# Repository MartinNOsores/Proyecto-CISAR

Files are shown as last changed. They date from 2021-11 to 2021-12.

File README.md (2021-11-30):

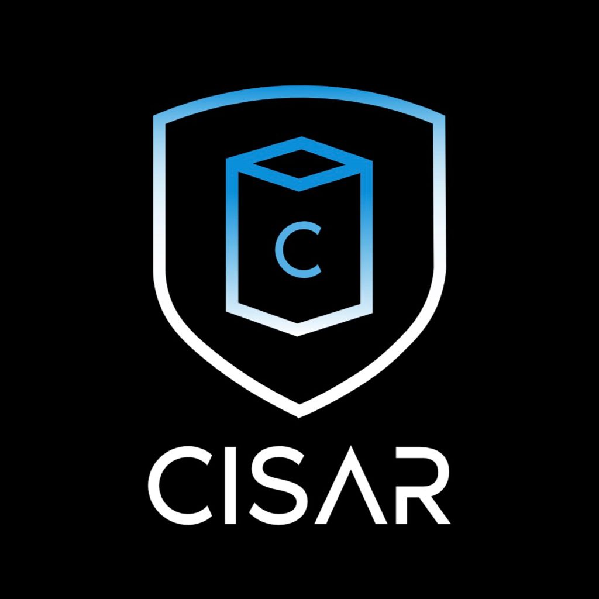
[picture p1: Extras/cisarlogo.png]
LogoCisar

# __Proyecto CISAR 2021 ™__

# Objetivo:
Nuestro proyecto “Cisar” consiste en un sistema de desinfección y monitoreo eficaz . Está pensado principalmente para que los lugares de gran cantidad de personas, que puedan tener un sistema de desinfección eficaz, controlada y organizada, previniendo el contagio de Covid-19, de todo el volumen de personas de manera automatizada, a través del uso adecuado del barbijo, control de temperatura corporal, la oxigenación en sangre e incitación a esterilizar las manos, el cuerpo en su totalidad y los objetos personales.
Para esto se construirá una cabina sanitizante y un control esterilizador de objetos personales.

# Temática:
Debido a la situación que estamos viviendo actualmente a nivel mundial, se debe tener una gran responsabilidad en relación a los cuidados que tomamos y más aún en lugares donde concurre un gran volumen de personas. Ante esta problemática nos topamos con un modelo de cuidado ineficiente, por ello nuestra propuesta consta de un aparato que nos ayude a lograr esos cuidados de la manera más eficiente posible, reduciendo considerablemente las posibilidades de contagio, logrando un eficiente control de multitudes. Este proyecto está pensado puntualmente para colegios y empresas donde tienen gran volumen de alumnos, hipermercados y fábricas.

# Descripción general:
Nuestra propuesta ante el Coronavirus y su repercusión a nivel mundial, es una cabina con la capacidad de tomar la temperatura de la persona que ingresa, sensar la oxigenación en sangre, desinfectar con un rociado alcohol en las manos, y de detectar la correcta posición del barbijo mediante una cámara, con Inteligencia Artificial .
Para su funcionamiento en régimen normal, el sistema estará enchufado a un cable de red común, de 220v.

Debe tener una cámara que mediante una Raspberry, y un programa ya entrenado de Inteligencia Artificial; identificará la correcta posición del barbijo, en este caso, le mostrará a la persona en una pantalla si está todo dentro de los parámetros correspondientes (Temperatura corporal, Oxigenación en sangre y el tapa boca), dándole acceso a la institución. De lo contrario, le indicará cómo debe ir colocado el tapabocas o cómo proceder ante la detección de una temperatura considerada como fiebre y dará aviso a las autoridades de la institución para que tengan la precaución correspondiente.

Se llevará un registro mediante el cual quedarán asentadas la cantidad de personas que ingresen a la institución, con su horario de ingreso respectivo, su temperatura, y si tenía bien colocado el tapabocas en el primer escaneo que realiza el sistema.

# Segmento de Usuario:
## Ventajas:
1. Desinfecta a los usuarios en cuestion de segundos.
2. No utiliza quimicos nocivos para la salud.
3. Promueve la higiene personal e incitacion a lavarse las manos.
4. Fomenta el cuidado del medio ambiente con el uso de materiales reciclados.
5. Garantiza espacios completamente libres de virus.

# Logros:
-  🥇 Project Idea ONIET 2021
-  🥇 Sello de Identidad ONIET 2021
 
# Integrantes:
  ## *Gonzalez Nuñéz Pedro*
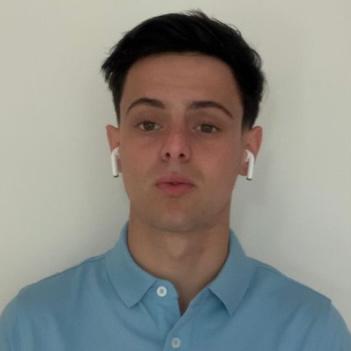
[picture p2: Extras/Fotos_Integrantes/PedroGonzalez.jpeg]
  
  ### Contacto: 
  - Instagram: @pedro_gonzalez_
---
  ## *Osores Martin Nicolás*
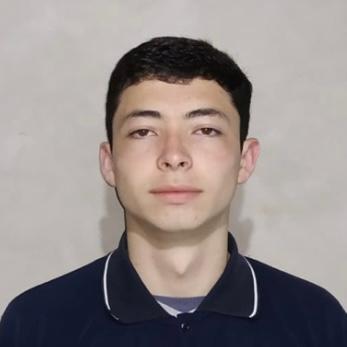
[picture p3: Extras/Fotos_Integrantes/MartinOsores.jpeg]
  
  ### Contacto: 
  - Instagram: @martin_osores_
---
  ## *Palacios Laureano*
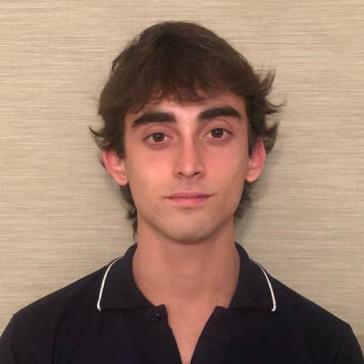
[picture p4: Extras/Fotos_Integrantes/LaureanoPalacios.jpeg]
  
  ### Contacto: 
  - Instagram: @laureanopalacios
---
  ## *Ruocco Julian Alberto*
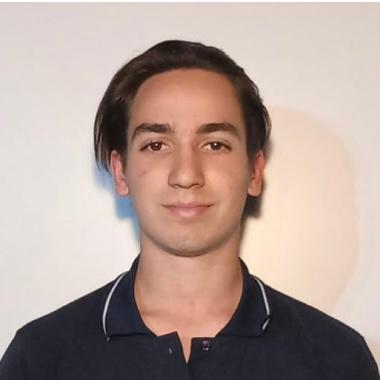
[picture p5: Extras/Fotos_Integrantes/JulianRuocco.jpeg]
  
   - Instagram: @julian_ruocco
---

## Nuestras Redes:
  - [Instagram (@cisar_cabinas_)](https://instagram.com/cisar_cabinas?utm_medium=copy_link)

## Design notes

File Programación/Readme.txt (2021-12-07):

Este apartado es dedicado a la programación, en el cual se incluirán los códigos de prueba y el main.

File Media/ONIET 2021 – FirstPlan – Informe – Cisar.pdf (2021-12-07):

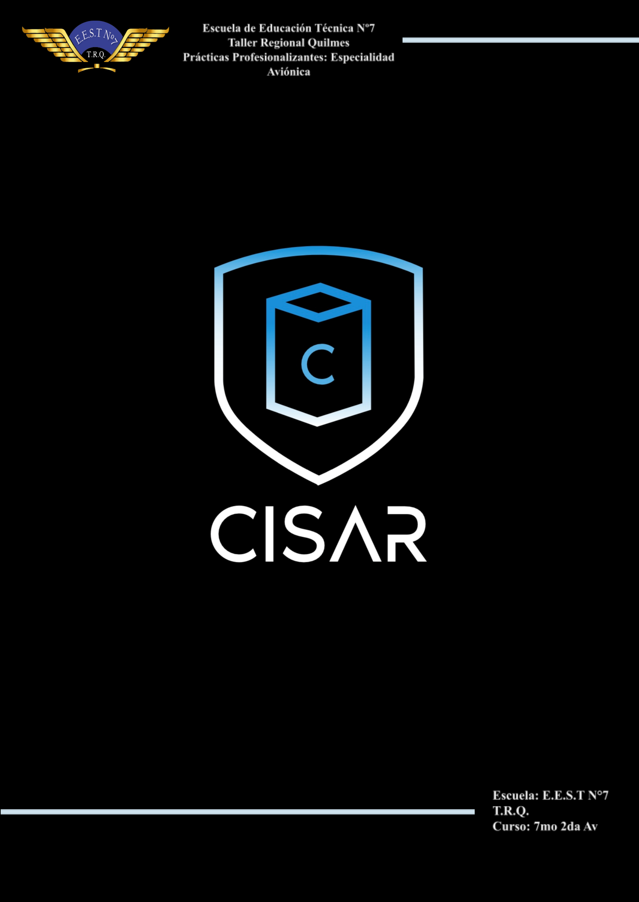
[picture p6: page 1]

# Introducción:

Descripción del producto: Cisar consiste en un sistema de desinfección y monitoreo focalizado para implementarse en lugares con gran concurrencia de personas. Este mismo consta de un sistema de desinfección corporal y objetos personales, de un control de acceso a los usuarios, un control del uso adecuado del barbijo y un control de enfermedades respiratorias.

# Informe de Canvas:

## Asociados clave:

Como asociados clave buscamos
- Para los insumos:
- Casa de electrónica como proveedor de componentes.
- Industria metalúrgica o entidades de reciclaje para el material estructural.
- Bulonera.
- Ferreteria industrial como proveedor de herramientas eléctricas.
- Casa de iluminación.
- Industria farmacéutica como proveedor del alcohol etílico.
- Colaboradores:
- Entidades de reciclaje
- Anmat
- Clientes con renta del producto.

## Actividades clave:

Como actividades clave tenemos:
- manejo de finanzas de manera que tengamos un buen margen de utilidad para destinar a reinversión.
- Servicio de logística: Encargada del envió del producto hasta el cliente
- Servicio de marketing por medio de redes sociales como instagram, facebook ads, contenido de youtube para atraer mayor inversión y llegar a mayores fronteras.
- Desarrollo del asistente virtual de manera que se proporcione ayuda al usuario.
- soporte al cliente, de manera que se garantice un correcto servicio hacia ellos.
- asistencia post-venta, para garantizar que al recibir el producto desarmado el cliente entienda cómo se debe armar el aparato.
- Servicio técnico para reparar el sistema o realizar calibraciones al producto.

## Recursos clave:

Los recursos clave con los que buscamos contar son:
- Estructura del producto.
- Plataforma tecnológica: Para permitir un espacio donde llevar a cabo
- Unidades de cómputo para permitir llevar a cabo todos los procesos del protocolo de Cisar.
- Plataforma de Telegram para contar con la interacción del asistente virtual.

## Propuesta de valor:

Como propuestas de valor ofrecemos:

- Reconocimiento del correcto uso del tapabocas.
- Una cabina autónoma con un control de acceso y de salud para los usuarios.
- Un sistema de desinfección de objetos personales con luces ultravioletas.
- Asistencia virtual de un bot de telegram para facilitar las interacciones entre la cabina y el usuario.
- Contamos con una estructura desmontable, para facilitar el traslado de la unidad.
- La aplicación de O3 para la sanitización del usuario.
- Ofrecemos la posibilidad de alquilar el producto en caso de no poder comprar el producto, donde el servicio técnico se ofrece gratuitamente.
●

●

Permite el cuidado entre los usuarios de una empresa

## Relación con los clientes:

La relación con los clientes se llevará a cabo mediante:
- Redes sociales:
- Instagram
- Facebook
- Whatsapp
- Tik Tok
- Sitio web

## Canales:

Los canales para llegar al cliente potencial se llevarán a cabo mediante:
- Instagram y Facebook, donde se contará con la página oficial de Cisar en perfil empresa de manera pública.
- Youtube, donde se subirán videos a manera de tutoriales por personal capacitado donde enseñarán todo lo necesario para utilizar el producto y se subirán videos enseñando los diversos sitios que cuentan con este producto y las ventajas que les trajo el utilizarlo.

- En Whatsapp y Telegram se contará con un perfil de empresa, el cual estará a disposición de las consultas de los usuarios.
- El Sitio web donde se mostrará geográficamente qué lugares utilizan Cisar y por qué así lo han decidido, además de infografías explicando el aparato y todas sus utilidades y aplicaciones.

## Segmento de clientes:

- Pymes que cuentan con oficinas.
- Fábricas con gran asistencia de personal.
- Hospitales con sectores de acceso especial.
- Laboratorios de análisis médicos.
- Instituciones educativas.

## Estructura de costos:

- Infraestructura tecnológica, principalmente la cabina y su electrónica.
- Servicio de logística para permitir el envío del producto.
- Servicio de marketing para lograr alcanzar a más clientes potenciales.
- Servicio técnico especializado para garantizar el correcto mantenimiento del producto.

## Vías de ingreso:

- Cobro por venta de unidad del producto.
- Tarifa variable con relación a la demanda del mismo producto.
- Cobro por alquiler de unidad del producto.
- Costo extra por especificaciones en la demanda del cliente (agregado).
- Métodos de pagos: Credito / Debito / Efectivo

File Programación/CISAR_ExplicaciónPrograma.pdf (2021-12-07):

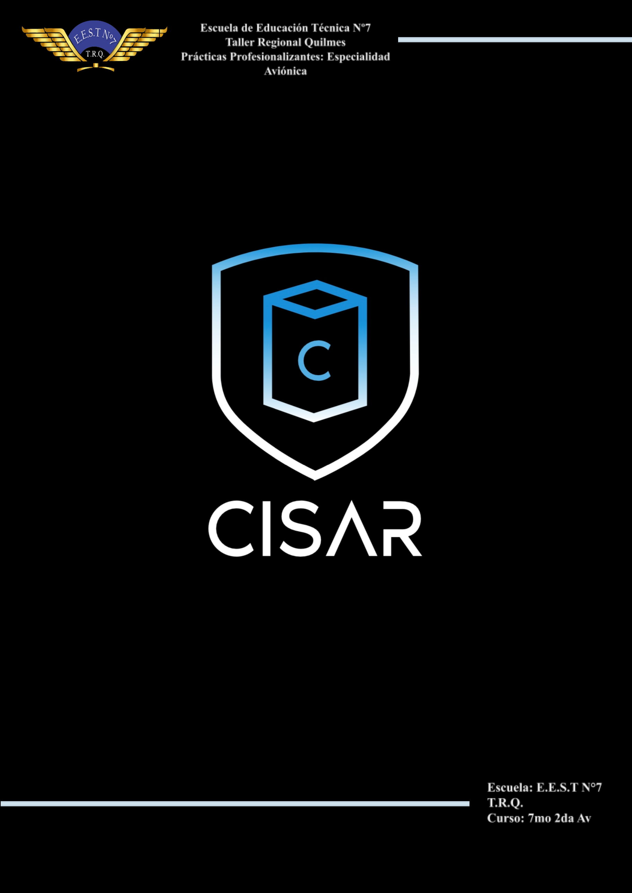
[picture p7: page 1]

# Explicación Programa Categoría: Project Idea

2021

### Informe descriptivo de la programación principal en Raspberry:

Empezamos importando las librerías que necesitamos:

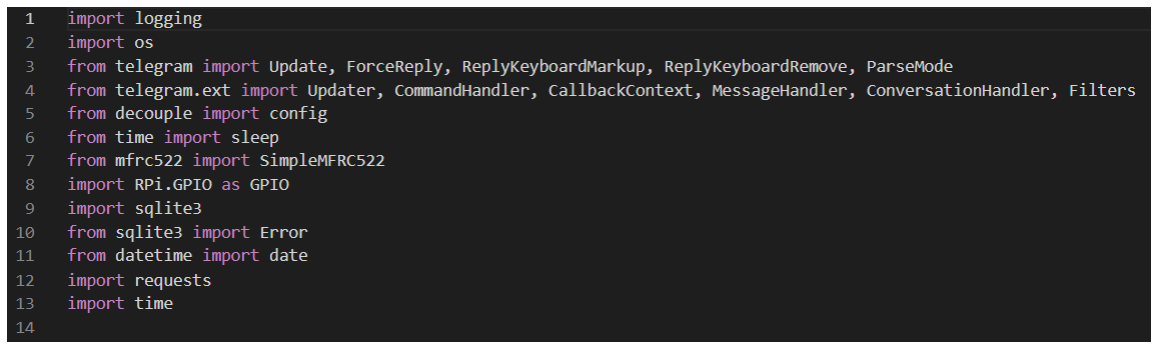
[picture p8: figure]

Creamos las variables y listas que necesitamos:

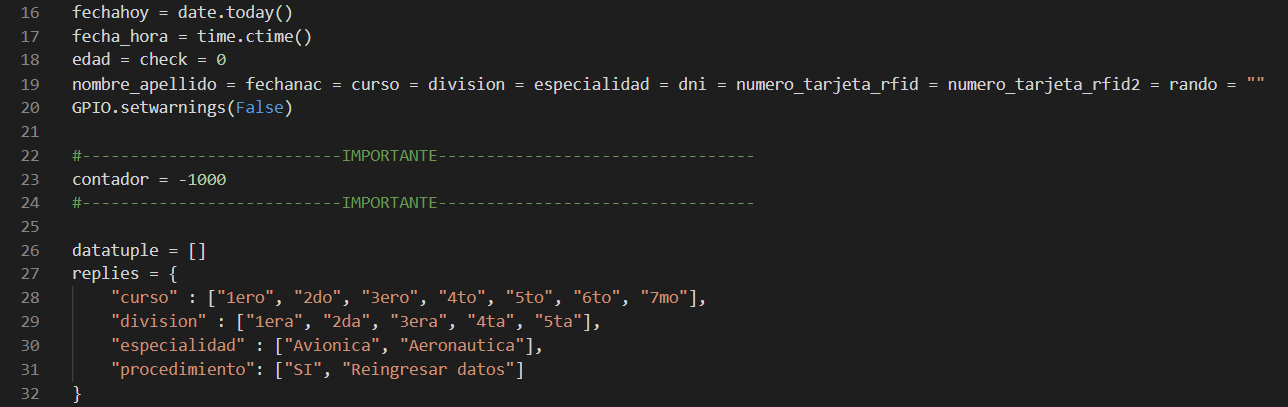
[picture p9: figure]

Se ejecuta el main, donde se inicializa el updater, dejando el programa a la escucha de recibir un mensaje:

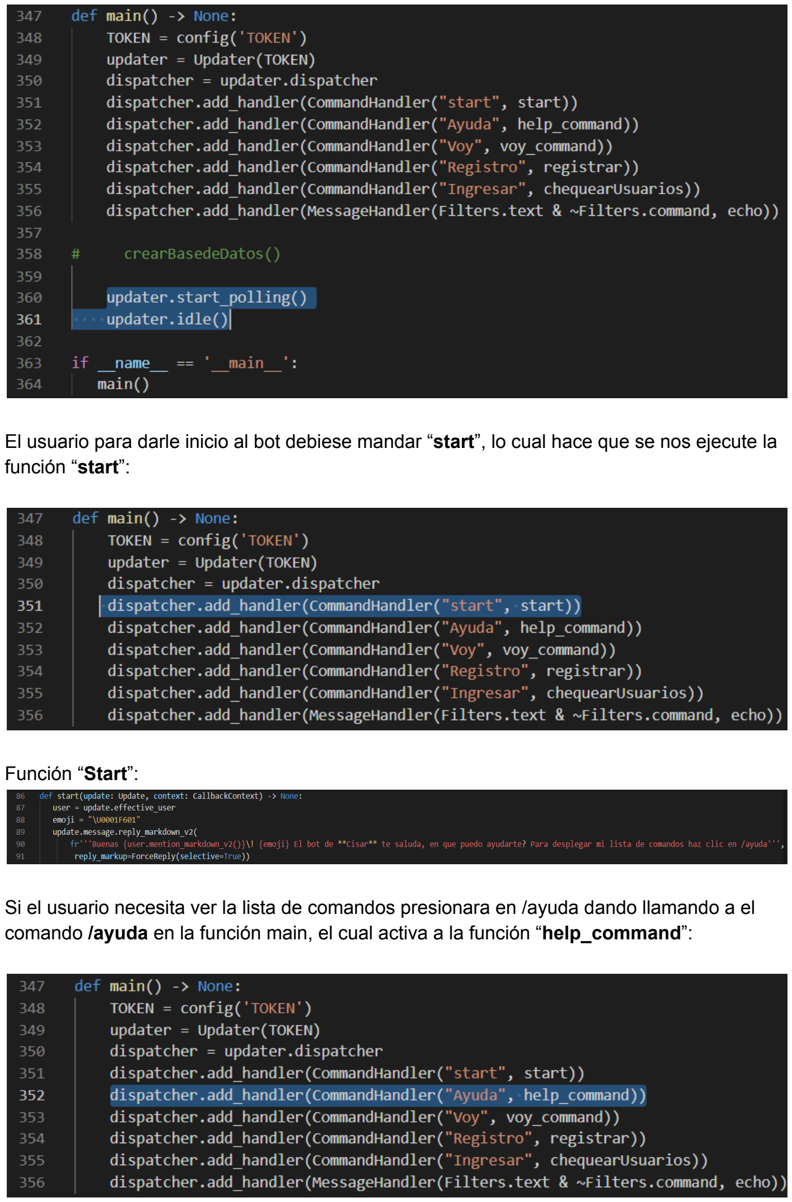
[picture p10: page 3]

El usuario para darle inicio al bot debiese mandar “start”, lo cual hace que se nos ejecute la función “start”:

Función “Start”:

Si el usuario necesita ver la lista de comandos presionara en /ayuda dando llamando a el comando /ayuda en la función main, el cual activa a la función “help_command”:

El usuario selecciona que comandó quiere utilizar:

- En el caso de seleccionar /Registro:
se llamará al comando /Registro dentro del main, donde este a su vez llamará a la función “Registrar”:

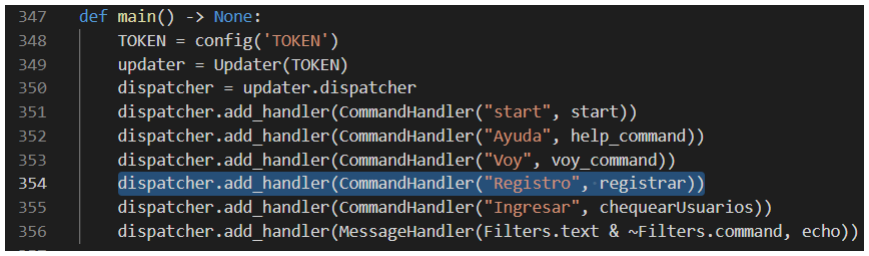
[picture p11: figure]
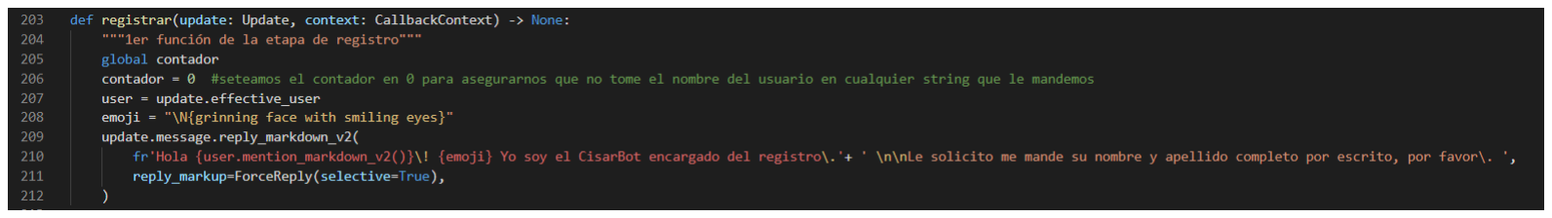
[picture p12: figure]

Nos solicitará que enviemos nuestro nombre y apellido completo, para lo cual mandaremos esto en formato de texto, dando como resultado el llamado a la función “echo” desde el main:

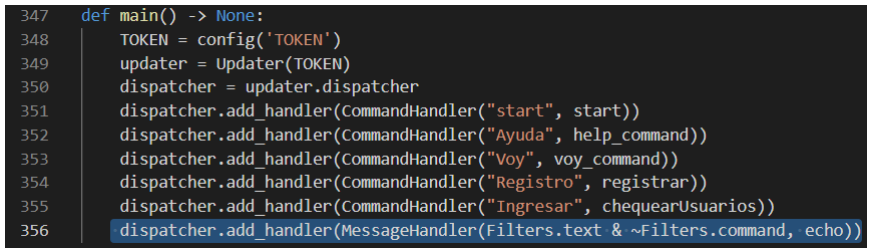
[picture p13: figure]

Previamente en la función “registrar” seteamos el contador en 0, de manera que cuando mandemos texto luego de dicha función, el programa entienda que es el nombre y apellido. En caso de mandar un nombre con números se seteara otra vez el contador en cero y se le solicitará al usuario su reingreso de este dato. Finalmente una vez que el usuario cargue un nombre válido se llamará a la función “registro_uno”:

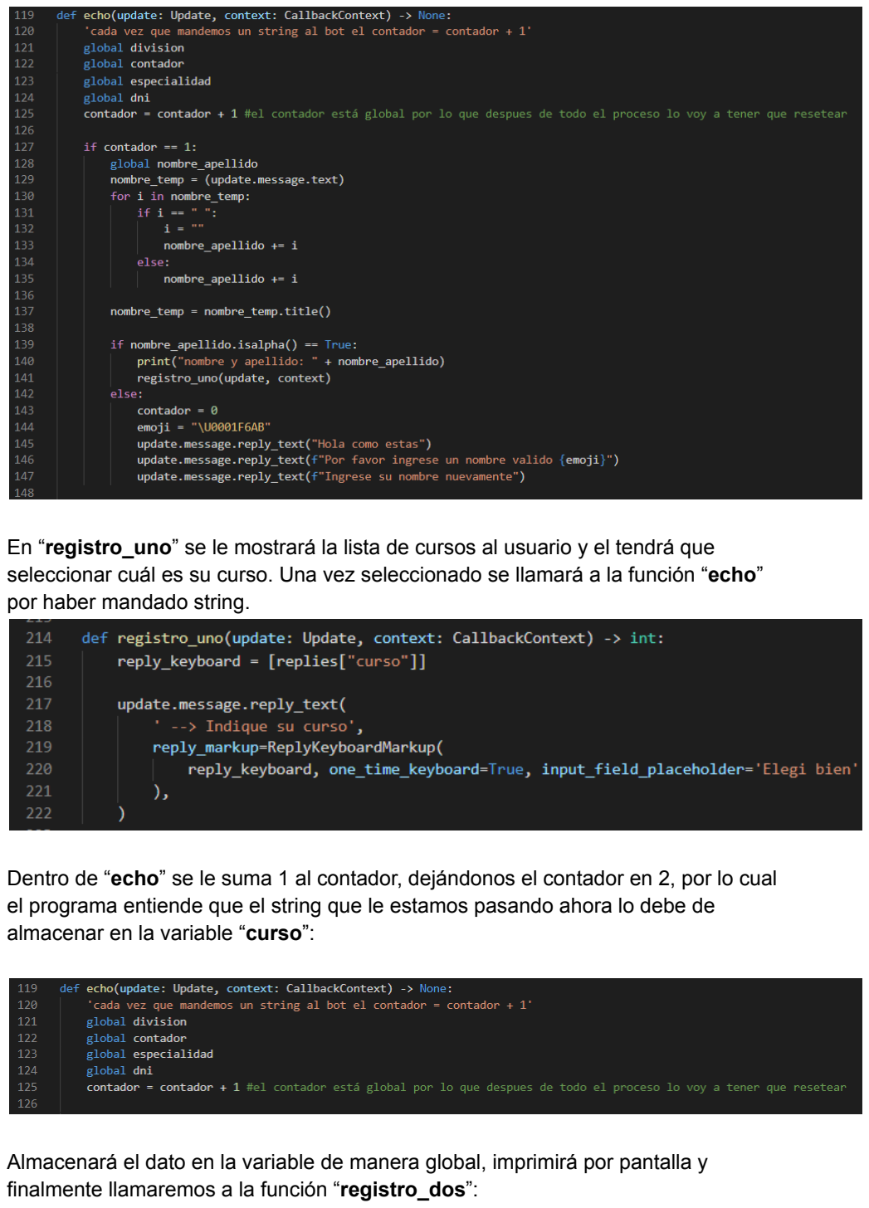
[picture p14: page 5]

En “registro_uno” se le mostrará la lista de cursos al usuario y el tendrá que seleccionar cuál es su curso. Una vez seleccionado se llamará a la función “echo” por haber mandado string.

Dentro de “echo” se le suma 1 al contador, dejándonos el contador en 2, por lo cual el programa entiende que el string que le estamos pasando ahora lo debe de almacenar en la variable “curso”:

Almacenará el dato en la variable de manera global, imprimirá por pantalla y finalmente llamaremos a la función “registro_dos”:

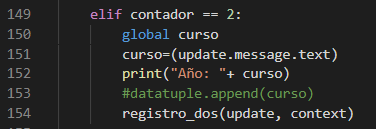
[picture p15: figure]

Dentro de la función “registro_dos” si el curso es 1ro, 2do o 3ero se mostrará la lista completa de divisiones para escoger a cuál pertenece. En caso de haber seleccionado previamente ser alumno de 4to, 5to, 6to o 7mo se mostrará la lista de divisiones recortando sólo las primeras 2 divisiones.
Una vez que el usuario seleccione su división se llamará a la función “echo”

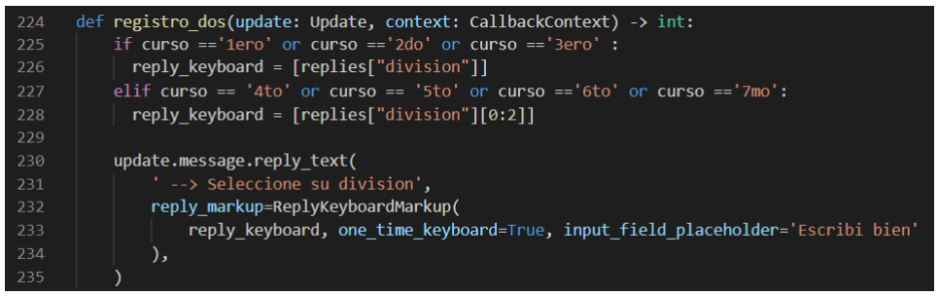
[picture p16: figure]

Al ingresar en “echo” aumenta el contador por lo cual tendría un valor de 3, con lo cual ingresará en la condición de que contador es 3, almacenará el string recibido en la variable (previamente declarada como global) “division”.
Si el curso seleccionado al momento de registrarse es 1ro, 2do o 3ero, imprimimos la división registrada y en la variable “especialidad” se almacenará un “-” y se llamará directamente a la función “registro_cuatro”.
En caso contrario, donde el curso del usuario en proceso de registro es 4to, 5to, 6to o 7mo, imprimimos por pantalla la división registrada y hacemos llamado a la función “registro_tres”:

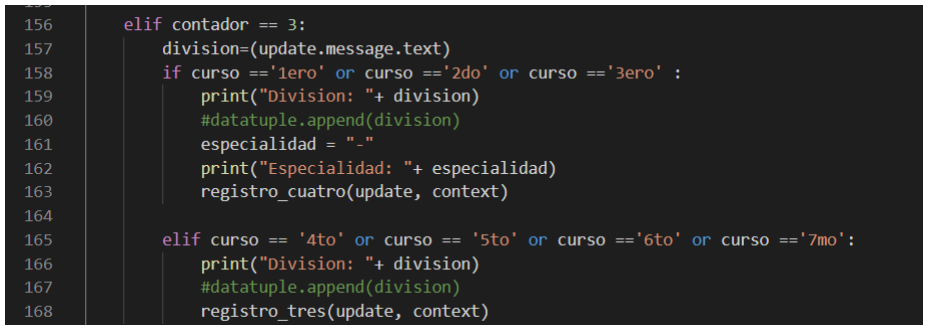
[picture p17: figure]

Se ejecuta “registro_tres”, donde se enseñará la lista de especialidad:

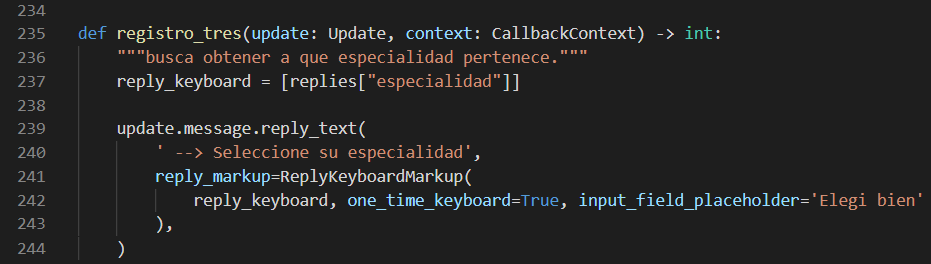
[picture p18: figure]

Una vez seleccionada la especialidad, se envía dicho string ingresando en la función “echo” aumentando el valor del contador en 1, dando como resultado que contador=4. Con la especialidad previamente definida como global, almacenamos el dato recibido en la variable “especialidad”, lo imprimimos por pantalla y realizamos el llamado de la función “registro_cuatro”:

Dentro de “registro_cuatro” declaramos al contador de manera global para posteriormente setearlo en 4 (esto es debido a que si el usuario coloco que pertenece a un curso de ciclo básico, su especialidad quedó definida como “-” y el contador se quedó en 3, debiendo estar en 4 para pasar al registro de DNI y así ingresar correctamente en el apartado de DNI dentro de “echo”).
Finalmente le solicitamos al usuario que ingrese por teclado su número de DNI:

Con la variable DNI declarada previamente como global dentro de “echo” indicamos que el string recibido debe ser almacenado en la variable “dni”, además de indicar que si el número introducido tiene más de 8 dígitos, se setea el contador en 4 y se llamará a la función “registro_seis”, donde se solicitará que reingrese el dni (permitimos que el dni ingresado sea menor a 8 debido a que algunos de estos no llegan a 8 dígitos).
Si el dni ingresado cumple con los requisitos mencionados se llamará a la función “chequeoDeDatos”:

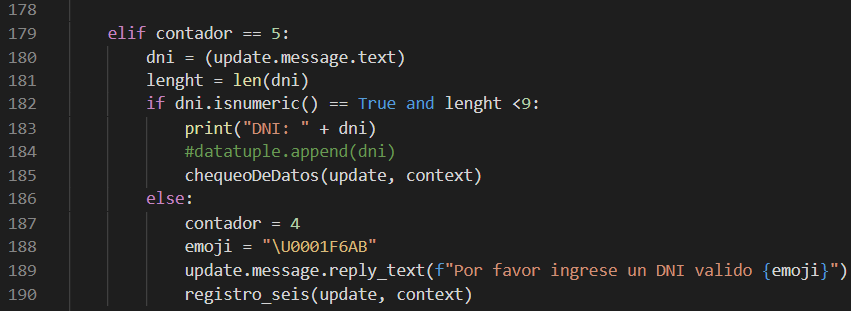
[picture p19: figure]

En “chequeoDeDatos” declaramos el contador de manera global, se ejecuta un mensaje pre-definido con los datos cargados por el usuario (almacenados en las variables) donde se pregunta si estos datos son correctos y se visualiza una lista de opciones “procedimiento” donde debe escoger entre “SI” o “Reingresar datos”.

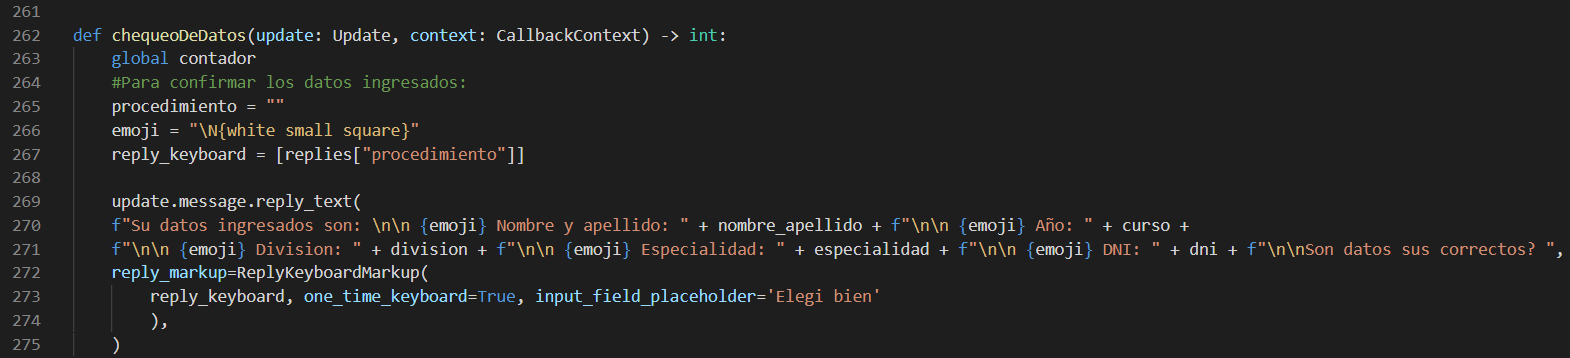
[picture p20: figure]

Una vez seleccionada la confirmación, ingresará en “echo” dando como resultado que contador = 6, donde se almacena el dato recibido en la variable local “procedimiento” y si seleccionó “Reingresar datos” el contador se seteará en -1000 (para evitar bugs) y se hará llamado a la función “registrar” para iniciar el proceso de registro desde 0.
En caso de haber seleccionado “SI” se llama a la función “registro_cinco”:

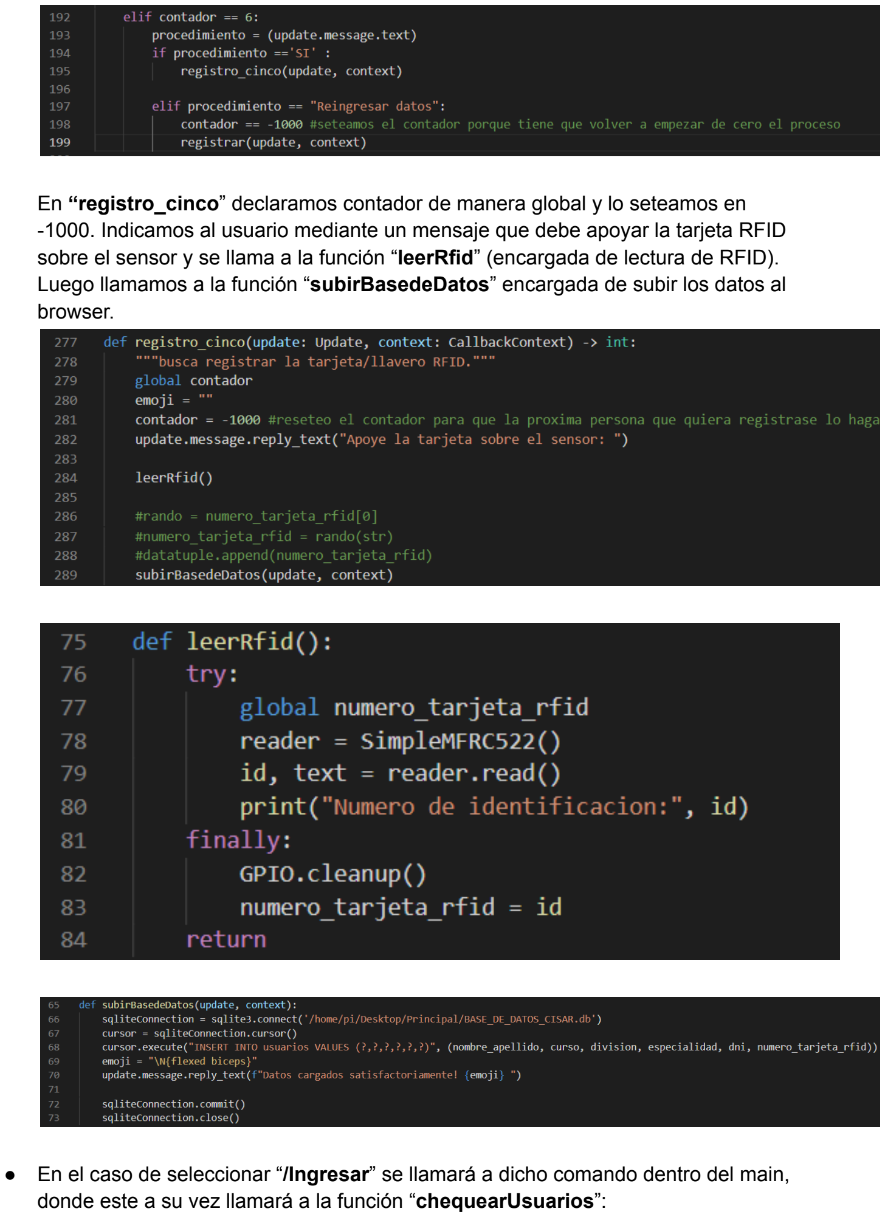
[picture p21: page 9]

En “registro_cinco” declaramos contador de manera global y lo seteamos en -1000. Indicamos al usuario mediante un mensaje que debe apoyar la tarjeta RFID sobre el sensor y se llama a la función “leerRfid” (encargada de lectura de RFID). Luego llamamos a la función “subirBasedeDatos” encargada de subir los datos al browser.

- En el caso de seleccionar “/Ingresar” se llamará a dicho comando dentro del main, donde este a su vez llamará a la función “chequearUsuarios”:

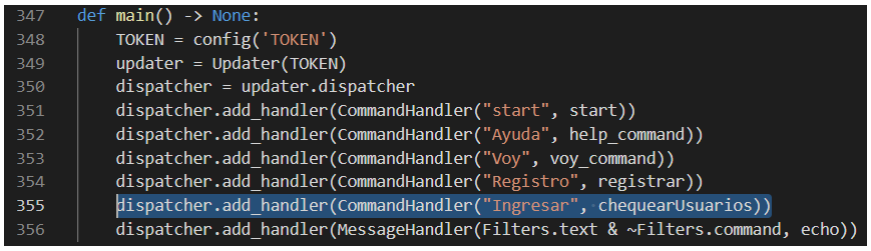
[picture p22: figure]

Dentro de la función “chequearUsuarios” se le enviará un mensaje al usuario indicando que debe apoyar la tarjeta sobre el sensor. Se llamará a la función encargada de la lectura del RFID “leerRfid” y se establecerá una conexión con el browser de la base de datos en búsqueda del número de identificación de la tarjeta asociado a un nombre, apellido, curso, división, especialidad y dni.
se declara la variable local “check” y se la setea en 0; de manera que el for se encargue de leer cada fila del registro tomado de la base de datos, una vez que encuentra al número de la tarjeta RFID almacenado en la base de datos toma el nombre, apellido, curso, división, especialidad y dni asociados a este número de tarjeta se le suma un 1 a “check” :

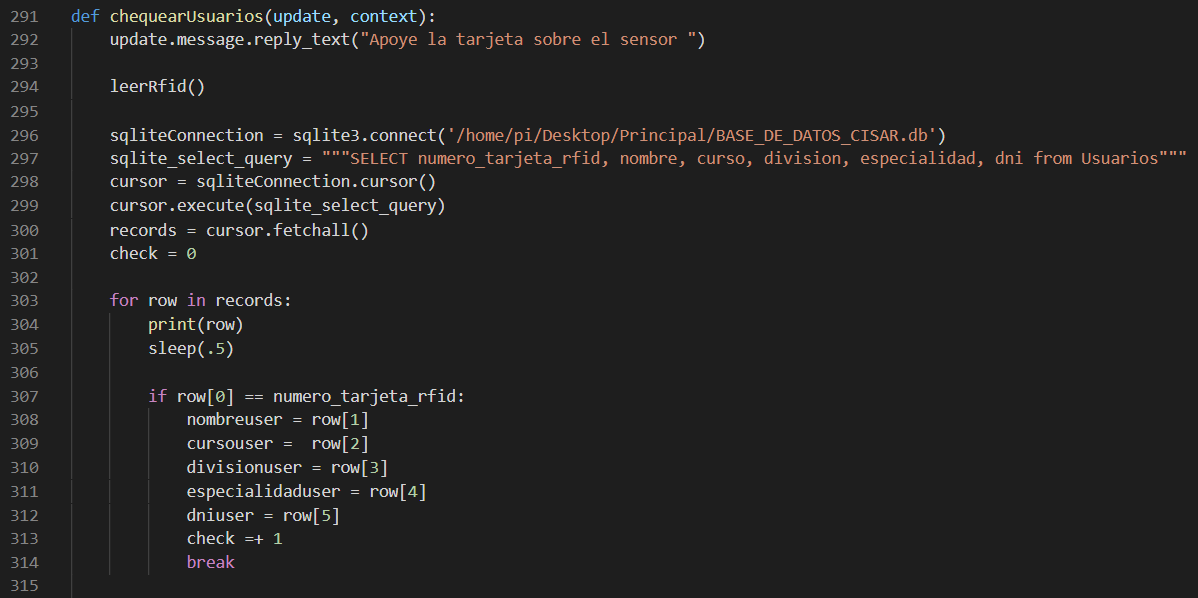
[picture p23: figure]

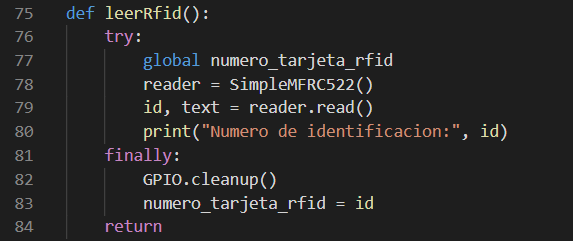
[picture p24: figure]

Por lo que evaluamos si “check” es mayor a 0, si es así declaramos a “pul” como variable global y enviamos un mensaje indicando al usuario que se encuentra en la base de datos, declaramos la variable local “pulsador” y le almacenamos el pin 40 de la Raspberry.
En cambio si “check” es igual a 0 se le envía un mensaje al usuario indicando que no se encuentra registrado en la base de datos y se ejecuta la función “ingreso_no_exitoso”.

Si recibimos un 1 (5V) desde la Arduino en el puerto de sensado de temperatura se ejecutará un mensaje pre-definido con las variables obtenidas de la base de datos previamente con destino el grupo de los directivos de la institución, a manera de alerta de sospechoso y se ejecutará la función “ingreso_sospechoso”
Por otro lado si no recibimos un 1 (5V) desde la Arduino en el puerto de sensado de temperatura se ejecutará la función “ingreso_exitoso”:

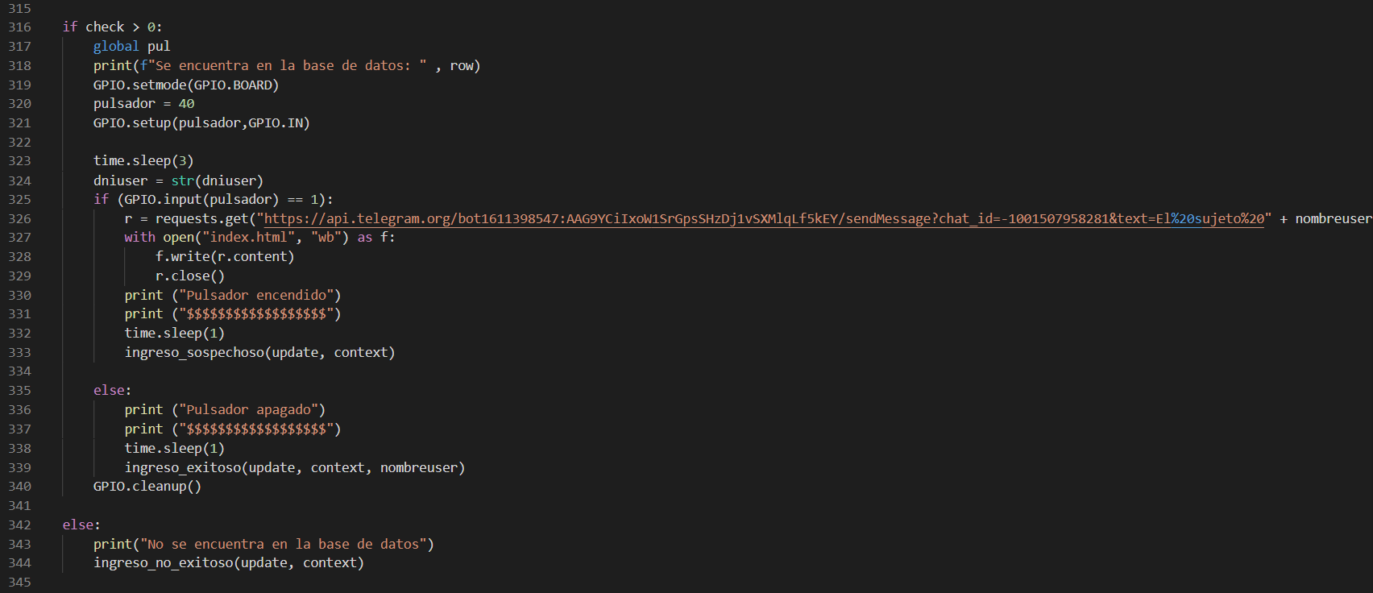
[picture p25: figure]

Dentro de la función “ingreso_exitoso”: Se le envía un mensaje al usuario indicando que puede ingresar a la cabina y deja un registro de fecha y hora del ingreso.

Dentro de la función “ingreso_sospechoso”: Se le envía un mensaje al usuario indicando que debe retirarse de la institución.

Dentro de la función “ingreso_no_exitoso”: Se le envía un mensaje al usuario indicando que no se encuentra registrado y se le enseña al usuario el comando para registrarse.

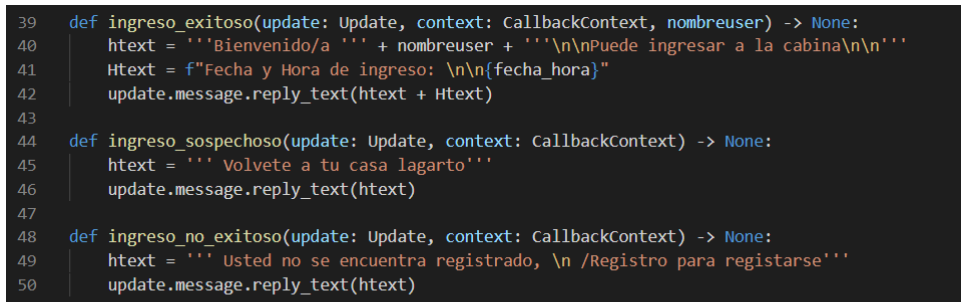
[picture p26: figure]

- En el caso de seleccionar /Voy, se llamará al comando /Voy dentro del main, donde este a su vez llamará a la función “voy_command”:

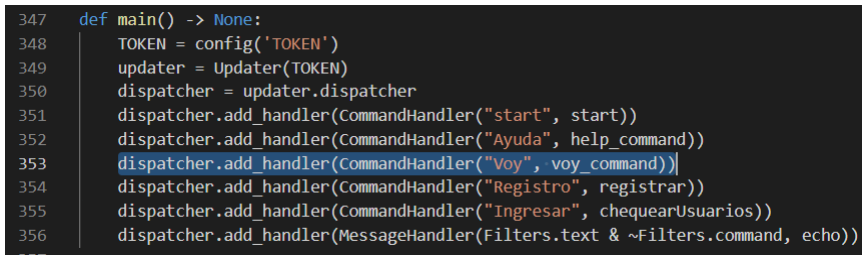
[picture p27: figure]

Se ejecuta la función “voy_command”, la cual envía le responde seleccionando el mensaje del usuario dentro del grupo de administración.

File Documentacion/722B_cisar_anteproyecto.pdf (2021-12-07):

Escuela de Educación Técnica Nº7
Taller Regional Quilmes
Prácticas Profesionalizantes: Especialidad Aviónica

# CISAR

## Presentación de anteproyecto

## Título del proyecto:

Tal como lo muestra el título vamos a realizar una cabina enfocada a la pandemia de COVID-19. Decidimos que el nombre del proyecto va a ser, CISAR (Cabina Integral Sanitizante Argentina), este nombre será especialmente utilizado para labores administrativas en este año, como también laborales en un futuro.

## Integrantes:

- GONZALEZ NUÑEZ, Pedro
- OSORES, Martín Nicolás
- PALACIOS, Laureano
- RUOCCO, Julián Alberto

## Objetivo del proyecto:

Nuestro proyecto “Cisar” consiste en un sistema de desinfección y monitoreo eficaz . Está pensado principalmente para que los lugares de gran cantidad de personas, que puedan tener un sistema de desinfección eficaz, controlada y organizada, previniendo el contagio de Covid-19, de todo el volumen de personas de manera automatizada, a través del uso adecuado del barbijo, control de temperatura corporal e incitación a esterilizar las manos, el cuerpo en su totalidad y los objetos personales.
Para esto se construirá una cabina sanitizante y un control esterilizador de objetos personales.

A continuación establecemos la construcción del proyecto en diversos objetivos:

1. Objetivo: Detectar los rostros del personal de la institución y dejar el registro de quién y a qué hora ingresó.
2. Objetivo: Sistema de sensado (sensor infrarrojo y sensor de temperatura), con rociador de alcohol.
3. Objetivo: Tener el generador de Ozono en funcionamiento.
4. Objetivo: Una estructura lo más hermética posible.
5. Objetivo: Sist de desinfección del calzado, Sensor de humedad
6. Objetivo: Página web.
7. Objetivo Opcional: Apartado pequeño con alcohol y luces ultravioleta para la sanitización de objetos personales (Como celular, billetera, etc).
8. Objetivo Opcional: Cabina especial para la desinfección de objetos personales

## Utilidades del proyecto:

Debido a la situación que estamos viviendo actualmente a nivel mundial, se debe tener una gran responsabilidad en relación a los cuidados que tomamos y más aún en lugares donde concurre un gran volumen de personas. Ante esta problemática nos topamos con un modelo de cuidado ineficiente, por ello nuestra propuesta consta de un aparato que nos ayude a lograr esos cuidados de la manera más eficiente posible, reduciendo considerablemente las posibilidades de contagio, logrando un eficiente control de multitudes. Este proyecto está pensado puntualmente para colegios y empresas donde tienen gran volumen de alumnos, hipermercados y fábricas.

A continuación comparto varios titulares de diferentes diarios que llevan a la misma conclusión, el virus durará un tiempo prolongado :

https://www.dw.com/es/opini%C3%B3n-el-coronavirus-lleg%C3%B3-para-quedarse/a-56113 832 (https://www.dw.com/es/opini%C3%B3n-el-coronavirus-lleg%C3%B3-para-quedarse/a-56113832)

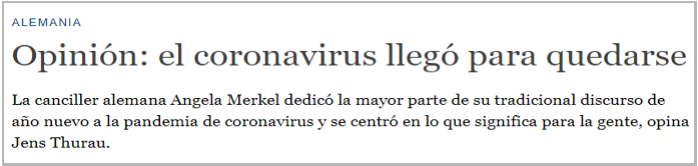
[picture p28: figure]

https://www.marca.com/tiramillas/actualidad/2021/03/18/605366d222601db9298b4597.html

https://www.lanacion.com.ar/politica/compra-de-vacunas-ya-se-gasto-la-mitad-del-presupuesto-y-solo-se-vacuno-al-099-de-la-poblacion-nid15032021/ (https://www.lanacion.com.ar/politica/compra-de-vacunas-ya-se-gasto-la-mitad-del-presupuesto-y-solo-se-vacuno-al-099-de-la-poblacion-nid15032021/)

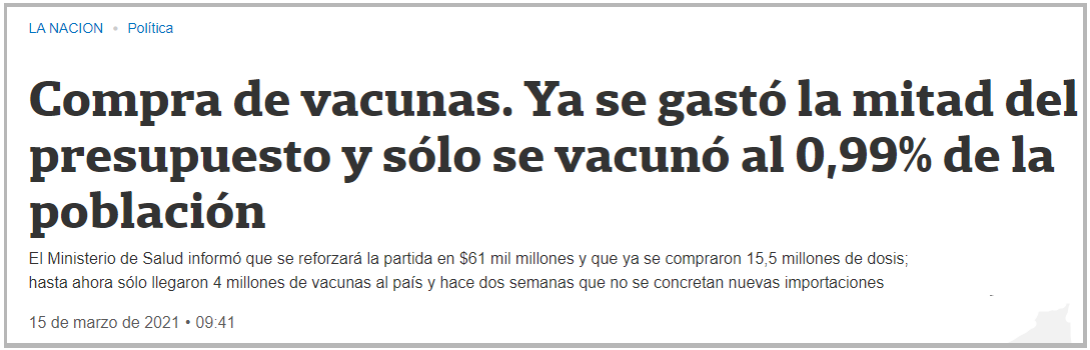
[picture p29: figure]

## Descripción del funcionamiento:

Nuestra propuesta ante el Coronavirus y su repercusión a nivel mundial, es una cabina con la capacidad de tomar la temperatura de la persona que ingresa, de desinfectar con un rociado alcohol en las manos, y de detectar la correcta posición del barbijo mediante una cámara, con Inteligencia Artificial .

Para su funcionamiento en régimen normal, el sistema estará enchufado a un cable de red común, de 220v. Pero tendrá una batería para poder continuar su funcionamiento al menos por dos días ante una emergencia eléctrica.

Debe tener una cámara que mediante una Raspberry, y un programa ya entrenado de Inteligencia Artificial; identificará la correcta posición del barbijo, en este caso, le mostrará a la persona en una pantalla si está todo dentro de los parámetros correspondientes (Temperatura corporal y el tapa boca) y le dará acceso a la institución. De lo contrario, le indicará cómo debe ir colocado el tapabocas o cómo proceder ante la detección de una temperatura considerada como fiebre y dará aviso a las autoridades de la institución para que tengan la precaución correspondiente.

Se llevará un registro mediante el cual quedarán asentadas la cantidad de personas que ingresen a la institución, con su horario de ingreso respectivo, su temperatura, y si tenía bien colocado el tapabocas en el primer escaneo que realiza el sistema.

## Análisis de factibilidad:

En este proyecto vamos a tener una gran variedad de tareas, donde se van a ver marcados en los siguientes puntos.

- Investigación:
- Acá vamos a desarrollar la información y las necesidades de cada parte del proyecto, incluyendo los alrededores del proyecto (condiciones/necesidades de las personas) para poder solucionar la mayor cantidad de problemas de cada persona. Los cuatro integrantes trabajaremos en este apartado para acotar tiempos y abarcar más puntos, además de que todos partamos desde la misma base.
- Investigando la proporción adecuada del uso del ozono, refracción de los espejos y sus ángulos para lograr una desinfección adecuada de los objetos.

- Diseño:
- Trabajaran Osores y Palacios, donde se utilizará principalmente el programa SolidWorks, donde haremos distintos prototipos de cabinas sanitizantes, para no quedarnos con simplemente uno.
- A partir de un prototipo veremos los materiales necesarios y gracias a esto podremos investigar el costo de cada uno.
- Estructura:
- Debe tener ciertas características, las cuales son: Poco peso, debe ser resistente, que sea de fácil armado/desarmado, que sea de fácil transporte, que no sea un material de corrosión rápida, que no sea un material poroso(para disminuir la adherencia de microorganismos indeseados), y que sea lo más económico posible.
- Estamos considerando la aplicación de hierro cuadrado y policarbonato alveolar.
- Página Web:
- Trabajarán Gonzalez y Ruocco, la van a hacer puramente con código, no se van a utilizar bases como las que ofrece “wix” o páginas por el estilo, sino que se van a usar las estructuras de HTML y los estilos con CSS.
- Sist de Ingreso de personas:
- Al ingresar una persona, primero tiene que dejar sus pertenencias en la máquina sanitizante de objetos, donde tendrá que seguir con el protocolo de ingreso. Para esto utilizaremos una lámpara led UV C y unos espejos que refractan la luz germicida para lograr una cobertura total.
- Al entrar, tiene que limpiarse el calzado en la alfombra desinfectante, donde se podrá tomar la temperatura, si no posee fiebre tiene que pasar las manos por el sensor infrarrojo, que se le agrega alcohol diluido con agua. Luego tendrá que ver hacia la cámara para poder saber si tiene bien puesto el barbijo, (gracias a la Inteligencia Artificial) se le mostrará cómo hacerlo.
- Dentro de la cabina hay un cierto margen de ozono en el ambiente, esto será previamente investigado para utilizar la proporción adecuada de ozono.
- Sistema de Actividad:
- Este sistema se desarrollará dentro de la IA (Inteligencia Artificial). Donde se podrá ver la cantidad de personas que entran y de ahí se podrá calcular la actividad por hora en ese mismo lugar. El cual será hecho con Python.

## Diagrama en bloques del prototipo:

Un diagrama en bloques muestra cada parte del sistema a finalizar y como se relacionan entre sí. Recomendamos el uso de miro (https://miro.com/) que es una herramienta muy práctica

Este es nuestro diagrama en bloques:


## Diagrama de tiempo de desarrollo:

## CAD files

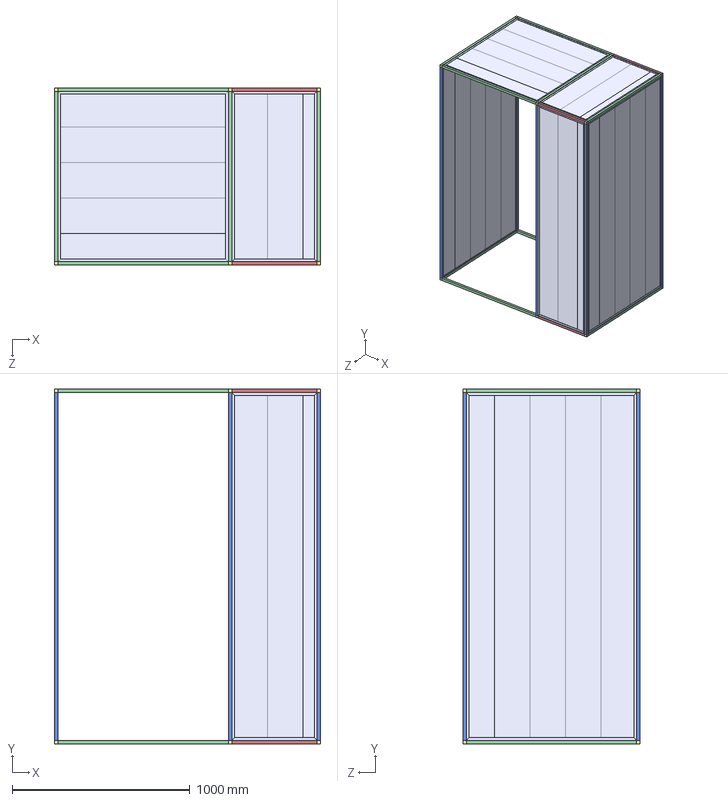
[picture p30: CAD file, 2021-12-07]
Modelado 3d/EnsamblajePrototipo.STEP
1500.0 x 2000.0 x 1000.0 mm
Ca隳 largo x 6
Ca隳 corto x 4
Ca隳 mediano x 10
Union 3 brazos x 8
Union 4 brazos x 4
Perfil J mediano (1mt) x 12
Perfil J Largo (2mt) x 10
Perfil J Corto (50cm) x 6
Tabla PVC 20cmx7mm Larga (2Mts) x 16
Tabla PVC 155mmx7mm Larga (2Mts) x 3
Tabla PVC 75mmx7mm Larga (2Mts) x 2
Tabla PVC 20cmx7mm Corta (1Mt) x 6
Tabla PVC 75mmx7mm Larga (1Mt)
Tabla PVC 155mmx7mm Corta(1Mt)

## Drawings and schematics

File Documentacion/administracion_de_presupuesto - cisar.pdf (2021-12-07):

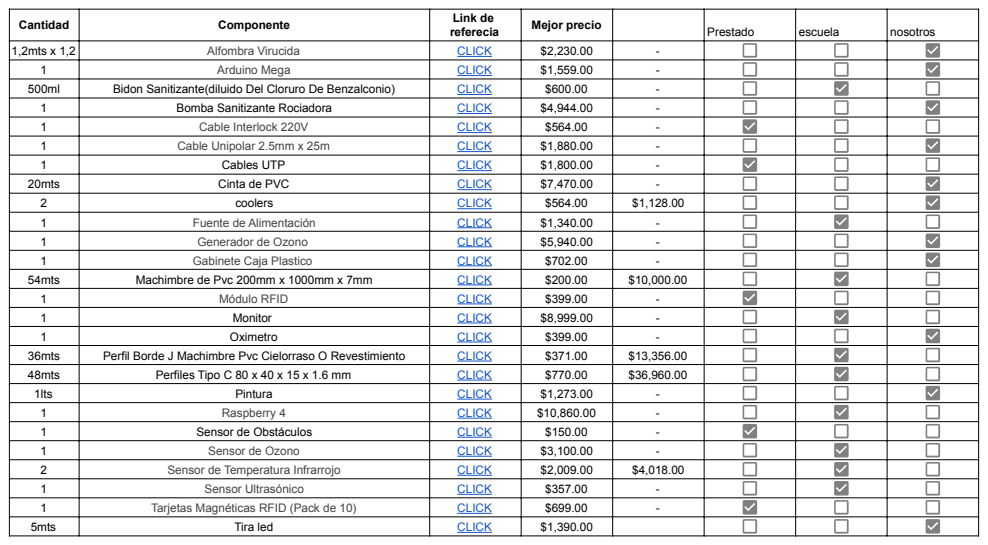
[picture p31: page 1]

Cantidad | Componente | Link de referecia | Mejor precio | | Prestado | escuela | nosotros

1,2mts x 1,2 | Alfombra Virucida | CLICK (https://articulo.mercadolibre.com.ar/MLA-919622455-felpudo-tapete-alfombra-rulo-pvc-con-base-120x1-_JM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) | $2,230.00 | -
1 | Arduino Mega | CLICK (https://articulo.mercadolibre.com.ar/MLA-677336910-placa-prototipado-arduino-mega-2560-robotica-usb-todomicro-_JM) | $1,559.00 | -
500ml | Bidon Sanitizante(diluido Del Cloruro De Benzalconio) | CLICK (https://articulo.mercadolibre.com.ar/MLA-867269065-bidon-sanitizantediluido-del-cloruro-de-benzanconio-_JM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) | $600.00 | -
1 | Bomba Sanitizante Rociadora | CLICK (https://articulo.mercadolibre.com.ar/MLA-687426829-bomba-presion-agua-1-gpm-12v-barcoagriculturacasa-rodante-_JM) | $4,944.00 | -
1 | Cable Interlock 220V | CLICK (https://articulo.mercadolibre.com.ar/MLA-898094478-cable-power-interlock-220-v-certificado-iram-pc-tv-ups-htec-_JM) | $564.00 | -
1 | Cable Unipolar 2.5mm x 25m | CLICK (https://articulo.mercadolibre.com.ar/MLA-1111308254-cable-unipolar-25-mm-x-100mts-l-_JM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) | $1,880.00 | -
1 | Cables UTP | CLICK (https://articulo.mercadolibre.com.ar/MLA-850808421-cable-rollo-50mts-50m-utp-exterior-cat-5e-red-tira-led-cctv-_JM) | $1,800.00 | -
20mts | Cinta de PVC | CLICK (https://articulo.mercadolibre.com.ar/MLA-844526452-cortina-bandas-de-plastico-carniceria-frigori-200x2mm-20-mts-_JM) | $7,470.00 | -
2 | coolers | CLICK (https://articulo.mercadolibre.com.ar/MLA-931106123-cooler-120mm-x-120mm-12v-molex-gabinetes-pc-caseros-_JM) | $564.00 | $1,128.00
1 | Fuente de Alimentación | CLICK (https://articulo.mercadolibre.com.ar/MLA-677070356-fuente-para-pc-500w-24-pines-sata-atx-pc-gtia-_JM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) | $1,340.00 | -
1 | Generador de Ozono | CLICK (https://articulo.mercadolibre.com.ar/MLA-914252520-ozonizador-placa-generadora-ozono-de-10-grh-para-canon-_JM) | $5,940.00 | -
1 | Gabinete Caja Plastico | CLICK (https://articulo.mercadolibre.com.ar/MLA-870973177-gabinete-caja-plastico-multiuso-proposit-40x70x55mm-gmi-htec-_JM) | $702.00 | -
54mts | Machimbre de Pvc 200mm x 1000mm x 7mm | CLICK (https://articulo.mercadolibre.com.ar/MLA-785495059-machimbre-de-pvc-blanco-200mm-x-7mm-_JM) | $200.00 | $10,000.00
1 | Módulo RFID | CLICK (https://articulo.mercadolibre.com.ar/MLA-905030984-kit-modulo-rfid-rc522-1356mhz-tag-tarjeta-llavero-arduino-_JM) | $399.00 | -
1 | Monitor | CLICK (https://articulo.mercadolibre.com.ar/MLA-1114923961-monitor-dell-19-modelo-e1909wc-19-con-cable-vga-_JM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) | $8,999.00 | -
1 | Oximetro | CLICK (https://articulo.mercadolibre.com.ar/MLA-923594022-sensor-de-pulso-cardiaco-oximetro-max30100-arduino-hobb-_JM) | $399.00 | -
36mts | Perfil Borde J Machimbre Pvc Cielorraso O Revestimiento | CLICK (https://articulo.mercadolibre.com.ar/MLA-846324329-perfil-j-terminacion-perimetral-para-cielorraso-10-mm-pvc-_JM) | $371.00 | $13,356.00
48mts | Perfiles Tipo C 80 x 40 x 15 x 1.6 mm | CLICK (https://articulo.mercadolibre.com.ar/MLA-651793077-perfil-c-de-chapa-galvanizado-80-x-40-x-15-x-16-mm-x-12mts-_JM) | $770.00 | $36,960.00
1lts | Pintura | CLICK (https://articulo.mercadolibre.com.ar/MLA-883867951-loxon-larga-duracion-interior-mate-x-1-lt-_JM) | $1,273.00 | -
1 | Raspberry 4 | CLICK (https://articulo.mercadolibre.com.ar/MLA-874945477-raspberry-pi-4-model-b-2gb-ram-video-4k-usb-c-_JM) | $10,860.00 | -
1 | Sensor de Obstáculos | CLICK (https://articulo.mercadolibre.com.ar/MLA-624602204-modulo-detector-sensor-de-obstaculos-infrarrojo-arduino-pic-_JM) | $150.00 | -
1 | Sensor de Ozono | CLICK (https://articulo.mercadolibre.com.ar/MLA-906556408-sensor-de-ozono-mq131-_JM) | $3,100.00 | -
2 | Sensor de Temperatura Infrarrojo | CLICK (https://articulo.mercadolibre.com.ar/MLA-778033748-sensor-temperatura-termometro-infrarrojo-mlx90614-gy-906-_JM) | $2,009.00 | $4,018.00
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

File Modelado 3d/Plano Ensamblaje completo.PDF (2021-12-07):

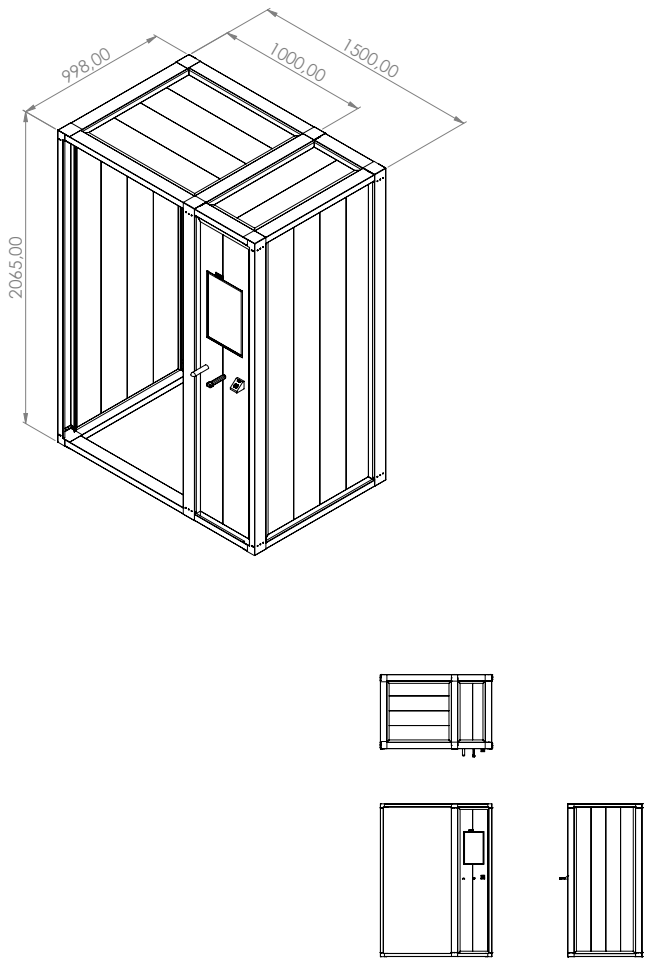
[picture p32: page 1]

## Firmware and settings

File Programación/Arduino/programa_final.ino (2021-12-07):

#include <stdio.h>
//#include <Adafruit_CircuitPlayground.h>
#include <Wire.h>
#include <Adafruit_MLX90614.h>
#include <MAX30105.h>
#include <spo2_algorithm.h>

Adafruit_MLX90614 mlx = Adafruit_MLX90614();
MAX30105 particleSensor;

byte MLXAddr = 0x5A<<1;
float medicion;
const int Trigger = 2;   
const int Echo = 3;   
//int luzroja = 7;
//int luzverde = 8;

// ----> COMUNICACION RASPBERRY
int flag_temp = 5;

// ----> RELAYS
int relay_generadorozono = 15;
int relay_coolers = 14;
int relay_bombarociador = 17;
int relay_lucesled = 16;

int sensorInflarojo = 4;
int a = 0; 
const int maxtemp = 37.5;

#define MAX_BRIGHTNESS 255

#if defined(_AVR_ATmega328P) || defined(AVR_ATmega168_)
//Arduino Uno doesn't have enough SRAM to store 100 samples of IR led data and red led data in 32-bit format
//To solve this problem, 16-bit MSB of the sampled data will be truncated. Samples become 16-bit data.
uint16_t irBuffer[100]; //infrared LED sensor data
uint16_t redBuffer[100];  //red LED sensor data
#else

uint32_t irBuffer[100]; //infrared LED sensor data
uint32_t redBuffer[100];  //red LED sensor data
#endif

int32_t bufferLength; //data length
int32_t spo2; //SPO2 value
int8_t validSPO2; //indicator to show if the SPO2 calculation is valid
int32_t heartRate; //heart rate value
int8_t validHeartRate; //indicator to show if the heart rate calculation is valid
byte pulseLED = 11; //Must be on PWM pin
byte readLED = 13; //Blinks with each data read

void setup() {
  Serial.begin(9600);
  Serial.println(" \n<-- Inicializando Monitor Serial --> \n ");
  mlx.begin();
  pinMode(Trigger, OUTPUT); 
  pinMode(Echo, INPUT);  
  pinMode(relay_generadorozono, OUTPUT);
  pinMode(relay_coolers, OUTPUT);
  pinMode(relay_bombarociador , OUTPUT);
  pinMode(relay_lucesled , OUTPUT);
  //pinMode(flagtemp, OUTPUT);
  pinMode(sensorInflarojo, INPUT);
  pinMode(pulseLED, OUTPUT);
  pinMode(readLED, OUTPUT);
  //pinMode(rociador, OUTPUT);
  //pinMode(luzroja, OUTPUT);
  //pinMode(luzverde, OUTPUT);
  delay(2000);
  
  digitalWrite(relay_generadorozono, HIGH);
   digitalWrite(relay_coolers , LOW); 
   digitalWrite(relay_bombarociador , LOW); 
   digitalWrite(relay_lucesled , LOW);
  digitalWrite(Trigger, LOW);
  delay(1000);

  // Initialize sensor
  if (!particleSensor.begin(Wire, I2C_SPEED_FAST)) //Use default I2C port, 400kHz speed
  {
    Serial.println(F("MAX30105 was not found. Please check wiring/power."));
    while (1);
  }
}

void loop(){
  
  long t; //tiempo que demora en llegar el eco
  long d; //distancia en centimetros

  digitalWrite(Trigger, HIGH);
  delayMicroseconds(10);          //Enviamos un pulso de 10us
  digitalWrite(Trigger, LOW);
  
  t = pulseIn(Echo, HIGH); //obtenemos el ancho del pulso
  d = t/59;             //escalamos el tiempo a una distancia en cm
  
  Serial.print("Distancia: ");
  Serial.print(d);      //Enviamos serialmente el valor de la distancia
  Serial.print("cm");
  Serial.println();
  delay(100);

  if (d < 170){
    medirTemperatura();
   }
   }
 void permitirIngreso() {
    digitalWrite(relay_coolers , HIGH);
    digitalWrite(relay_lucesled , HIGH);
    
    digitalWrite(relay_generadorozono, HIGH);
    delay(3000);
    digitalWrite(relay_generadorozono, LOW);

    delay(12000);
    digitalWrite(relay_coolers , LOW);
    digitalWrite(relay_lucesled , LOW);

    // AVISARLE A LA RASPBERRY QUE SALÍO LA PERSONA   
    }
 
void medirTemperatura(){                                                                    
  Wire.begin(15);
  int i=0;
  while(i<5){
    i= i + 1;
    delay (3000); // damos un tiempo para medirse la temp. de 3 seg.
    float medicion = mlx.readObjectTempC();
    float medicion_corregida = medicion * 1.152; //calibramos la medición de temperatura mediante un factor
    
    Serial.println("Temperatura: ");
    Serial.print(mlx.readObjectTempC());
    Serial.println("Cº");
  }
    delay(1000);
  
    if ( medicion > 20 && medicion <40) {
    Serial.println("\nComenzando medicion de la saturacion\n");
    delay(1000);
    
    medirsaturacion();
      }
    else {
      exit;
    //mandarle un 1 a la raspberry

      }    
}

void medirDistanciaRociador(){
  delay(5000); //damos un tiempo de 5 seg.
  int flag = 1; 
 while (flag) {
 
  if (digitalRead(sensorInflarojo) == LOW){     
      Serial.println("\nObstaculo Detectado\n");
      digitalWrite(relay_bombarociador, HIGH);
      delay(1000);
      digitalWrite(relay_bombarociador, LOW);
      flag = 0;
      }}

      permitirIngreso();
     
  }

  void medirsaturacion(){
  Wire.begin(24) ;
  Serial.read();

  byte ledBrightness = 60; //Options: 0=Off to 255=50mA
  byte sampleAverage = 4; //Options: 1, 2, 4, 8, 16, 32
  byte ledMode = 2; //Options: 1 = Red only, 2 = Red + IR, 3 = Red + IR + Green
  byte sampleRate = 100; //Options: 50, 100, 200, 400, 800, 1000, 1600, 3200
  int pulseWidth = 411; //Options: 69, 118, 215, 411
  int adcRange = 4096; //Options: 2048, 4096, 8192, 16384

  particleSensor.setup(ledBrightness, sampleAverage, ledMode, sampleRate, pulseWidth, adcRange); //Configure sensor with these settings
  
  delay(5000); // damos un retardo de 5 seg.
  int contador = 0;
  bufferLength = 100; //buffer length of 100 stores 4 seconds of samples running at 25sps

  //read the first 100 samples, and determine the signal range
  for (byte i = 0 ; i < bufferLength ; i++)
  {
    while (particleSensor.available() == false) //do we have new data?
      particleSensor.check(); //Check the sensor for new data

    redBuffer[i] = particleSensor.getRed();
    irBuffer[i] = particleSensor.getIR();
    particleSensor.nextSample(); //We're finished with this sample so move to next sample

    Serial.print(F("red="));
    Serial.print(redBuffer[i], DEC);
    Serial.print(F(", ir="));
    Serial.println(irBuffer[i], DEC);
  }

  //calculate heart rate and SpO2 after first 100 samples (first 4 seconds of samples)
  maxim_heart_rate_and_oxygen_saturation(irBuffer, bufferLength, redBuffer, &spo2, &validSPO2, &heartRate, &validHeartRate);

    //dumping the first 5 sets of samples in the memory and shift the last 75 sets of samples to the top
    for (byte i = 25; i < 30; i++)
    {
      redBuffer[i - 25] = redBuffer[i];
      irBuffer[i - 25] = irBuffer[i];
    }
    
    //take 1 set of sample before calculating the heart rate.
    for (byte i = 75; i < 80; i++)
    {
      while (particleSensor.available() == false) //do we have new data?
        particleSensor.check(); //Check the sensor for new data

      digitalWrite(readLED, !digitalRead(readLED)); //Blink onboard LED with every data read

      redBuffer[i] = particleSensor.getRed();
      irBuffer[i] = particleSensor.getIR();
      particleSensor.nextSample(); //We're finished with this sample so move to next sample

      //send samples and calculation result to terminal program through UART
      Serial.print(F("red="));
      Serial.print(redBuffer[i], DEC);
      Serial.print(F(", ir="));
      Serial.print(irBuffer[i], DEC);
      Serial.print(F(", HR="));
      Serial.print(heartRate, DEC);
      Serial.print(F(", HRvalid="));
      Serial.print(validHeartRate, DEC);
      Serial.print(F(", SPO2="));
      Serial.print(spo2, DEC);
      Serial.print(F(", SPO2Valid="));
      Serial.println(validSPO2, DEC);

    //After gathering 25 new samples recalculate HR and SP02
    maxim_heart_rate_and_oxygen_saturation(irBuffer, bufferLength, redBuffer, &spo2, &validSPO2, &heartRate, &validHeartRate);
  }
  medirDistanciaRociador();
  }

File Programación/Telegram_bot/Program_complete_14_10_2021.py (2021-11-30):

import logging
import os
from telegram import Update, ForceReply, ReplyKeyboardMarkup, ReplyKeyboardRemove, ParseMode
from telegram.ext import Updater, CommandHandler, CallbackContext, MessageHandler, ConversationHandler, Filters
from decouple import config
from time import sleep
from mfrc522 import SimpleMFRC522
import RPi.GPIO as GPIO
import sqlite3 
from sqlite3 import Error
from datetime import date
import requests
import time


fechahoy = date.today()
fecha_hora = time.ctime()
edad = check = 0
nombre_apellido = fechanac = curso = division = especialidad = dni = numero_tarjeta_rfid = numero_tarjeta_rfid2 = rando = ""
GPIO.setwarnings(False)

#---------------------------IMPORTANTE---------------------------------
contador = -1000
#---------------------------IMPORTANTE---------------------------------

datatuple = []
replies = {
    "curso" : ["1ero", "2do", "3ero", "4to", "5to", "6to", "7mo"],
    "division" : ["1era", "2da", "3era", "4ta", "5ta"],
    "especialidad" : ["Avionica", "Aeronautica"],
    "procedimiento": ["SI", "Reingresar datos"]
}

logging.basicConfig(
   format='%(asctime)s - %(name)s - %(levelname)s - %(message)s',
   level=logging.INFO)
logger = logging.getLogger(__name__)

def ingreso_exitoso(update: Update, context: CallbackContext, nombreuser) -> None:
    htext = '''Bienvenido/a ''' + nombreuser + '''\n\nPuede ingresar a la cabina\n\n'''
    Htext = f"Fecha y Hora de ingreso: \n\n{fecha_hora}"
    update.message.reply_text(htext + Htext)

def ingreso_sospechoso(update: Update, context: CallbackContext) -> None:
    htext = ''' Debe volver a su hogar'''
    update.message.reply_text(htext)

def ingreso_no_exitoso(update: Update, context: CallbackContext) -> None:
    htext = ''' Usted no se encuentra registrado, \n /Registro para registarse'''
    update.message.reply_text(htext)
    
def crearBasedeDatos():
    sqliteConnection = sqlite3.connect('/home/pi/Desktop/Principal/BASE_DE_DATOS_CISAR.db')
    cursor = sqliteConnection.cursor()

    cursor.execute("""CREATE TABLE usuarios (    
                            nombre text,
                            curso integer,
                            division integer,
                            especialidad integer,
                            dni integer,
                            numero_tarjeta_rfid integer
                            )""");

def subirBasedeDatos(update, context):
    sqliteConnection = sqlite3.connect('/home/pi/Desktop/Principal/BASE_DE_DATOS_CISAR.db')
    cursor = sqliteConnection.cursor()
    cursor.execute("INSERT INTO usuarios VALUES (?,?,?,?,?,?)", (nombre_apellido, curso, division, especialidad, dni, numero_tarjeta_rfid))
    emoji = "\N{flexed biceps}"
    update.message.reply_text(f"Datos cargados satisfactoriamente! {emoji} ")
    
    sqliteConnection.commit()
    sqliteConnection.close()

def leerRfid():
    try:
        global numero_tarjeta_rfid
        reader = SimpleMFRC522()
        id, text = reader.read()
        print("Numero de identificacion:", id)
    finally:
        GPIO.cleanup()
        numero_tarjeta_rfid = id
    return

def start(update: Update, context: CallbackContext) -> None:
   user = update.effective_user
   emoji = "\U0001F601" 
   update.message.reply_markdown_v2(
       fr'''Buenas {user.mention_markdown_v2()}\! {emoji} El bot de **Cisar** te saluda, en que puedo ayudarte? Para desplegar mi lista de comandos haz clic en /ayuda''',
        reply_markup=ForceReply(selective=True))
   

def voy_command(update: Update, context: CallbackContext) -> None:
   htext = '''Usted se está comprometiendo con proceder con el posible sospechoso, tenga cuidado.'''
   update.message.reply_text(htext)

def help_command(update: Update, context: CallbackContext) -> None:
    htext = "Mi lista de comandos: \n\n --> \t/Registro (Le permite registarse como alumno)\n\n --> \t/Ingresar (busca iniciar el protocolo de ingreso)\n\n --> \t/voy (usted se ocupa del sospechoso)"
    update.message.reply_text(htext)

def calcularEdad(fechanac):
    
    fechahoy = date.today()
    day = int((fechanac[0:2]))
    month = int((fechanac[3:5]))
    year = int((fechanac[6:]))
    
    #if (year > fechahoy.year): #or month > fechahoy.month or day > fechahoy.day:
        #print("\n [!] Ingrese una fecha de nacimiento valida [!]")
        #exit()
    #else:
        #pass
    
    edad = fechahoy.year - year - ((fechahoy.month, fechahoy.day) < (month, day))

    return edad
    
def echo(update: Update, context: CallbackContext) -> None:
    'cada vez que mandemos un string al bot el contador = contador + 1'
    global division
    global contador
    global especialidad
    global dni
    contador = contador + 1 #el contador está global por lo que despues de todo el proceso lo voy a tener que resetear

    if contador == 1:
        global nombre_apellido
        nombre_temp = (update.message.text)
        for i in nombre_temp:
            if i == " ":
                i = ""
                nombre_apellido += i
            else:
                nombre_apellido += i
                
        nombre_temp = nombre_temp.title()
            
        if nombre_apellido.isalpha() == True:
            print("nombre y apellido: " + nombre_apellido)
            registro_uno(update, context)
        else:
            contador = 0
            emoji = "\U0001F6AB"
            update.message.reply_text("Hola como estas")
            update.message.reply_text(f"Por favor ingrese un nombre valido {emoji}")
            update.message.reply_text(f"Ingrese su nombre nuevamente")
        
    elif contador == 2:
        global curso
        curso=(update.message.text)
        print("Año: "+ curso)
        #datatuple.append(curso)
        registro_dos(update, context)
    
    elif contador == 3:
        division=(update.message.text)
        if curso =='1ero' or curso =='2do' or curso =='3ero' :
            print("Division: "+ division)
            #datatuple.append(division)
            especialidad = "-"
            print("Especialidad: "+ especialidad)
            registro_cuatro(update, context)
            
        elif curso == '4to' or curso == '5to' or curso =='6to' or curso =='7mo':
            print("Division: "+ division)
            #datatuple.append(division)
            registro_tres(update, context)
    
    elif contador == 4:
        especialidad=(update.message.text)
        print("Especialidad: "+ especialidad)
        registro_cuatro(update, context)
        
    #elif contador == 6:
        #datatuple.append(especialidad)
        #registro_cuatro(update, context)
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

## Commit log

2021-05-04 fait: agregue los sensores que vamos a utilizar
2021-05-04 feat: adjunto los archivos de prueba de audio
2021-09-10 Programa de la base de datos con sensor RFID
2021-09-10 Sensor RFID con base de datos v0.1
2021-09-14 Add files via upload
    Bot de telegram con las funciones de registro e informacion sobre sospechoso
2021-09-15 feat: bot telegram funcion SELECT
    Adjunto carpeta con el programa que busca tarjetas rfid y tambien adjunto la base de batos que contiene las tarjetas
2021-09-22 Create Api_activador_de_URL.py
    Programa que ejecuta la api sobre la deteccion de un sospechoso
2021-09-22 feature
    Arregamos el token y el chat id
2021-09-24 feat: formato programa
    acomodar el formato del programa y eliminar comentarios innecesarios
2021-09-24 feat: ajustes minimos de formato
2021-09-26 Add
    Programa que busca eliminar excesivos llamados a funciones por escrito
2021-09-28 feat: programa para probar
2021-11-09 Libreria I2C master
2021-11-30 style: corregir el md visualmente
2021-11-30 refactor: organizar el repositorio
2021-11-30 style: agregar imagenes de miembros en el readme
2021-12-07 chore: Modificar la ubicacion del Logo
2021-12-07 chore: se incorpora el prototipo de la cabina en 3d
    [EnsamblajePrototipo.STEP]
2021-12-07 docs: Carpeta que incluye toda la programación
2021-12-07 chore: agregado del programa faceid en carpeta de programacion
2021-12-07 chore: Se agrega animacion de ensamblaje basico
2021-12-07 docs: migracion del .ino final a la carpeta de programacion
2021-12-07 chore: agregado de documentos web en links
2021-12-07 docs: migracion del .py final a carpeta de programacion
2021-12-07 chore: agregado de la explicacion del programa .py final
2021-12-07 chore: Add video de presentacion en media
2021-12-07 docs: migracion de librerias a programacion
2021-12-07 docs: migracion de librearias a arduino
2021-12-07 chore: Se agrega el plano general y el ensamblaje
2021-12-07 docs: migracion de fotos de integrantes
2021-12-07 docs: migracion de registro&DB a Programación
2021-12-07 docs: Se modifica la ubicación de un programa de prueba
2021-12-07 docs: Se migra carpeta de prueba dentro de Programación
2021-12-07 docs: migración de Tk a Programación
2021-12-07 docs: elimiación de carpeta basura
